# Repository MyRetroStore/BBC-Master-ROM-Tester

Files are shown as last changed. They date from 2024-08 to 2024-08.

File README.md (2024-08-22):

# BBC Master ROM Dumper
An Arduino Mega shield to read and verify the BBC Master 1MBit ROM and compares the ROM images to known CRC-32 values for various ROMs.

## Introduction
Modern EPROM programmers like the TL866 are unable to read the 28 pin 1Mbit ROM used in the BBC Master.  If you are troubleshooting a BBC Master and you don't have a known good BBC Master to test the ROM in, this makes it difficult to troubleshoot. 

I built a shield for the Arduino Mega 2560 which reads the ROM and compares the CRC-32 hash values to know good ROMs found on the internet with a option of displaying the contents of the ROM via the Arduino IDE serial monitor. 

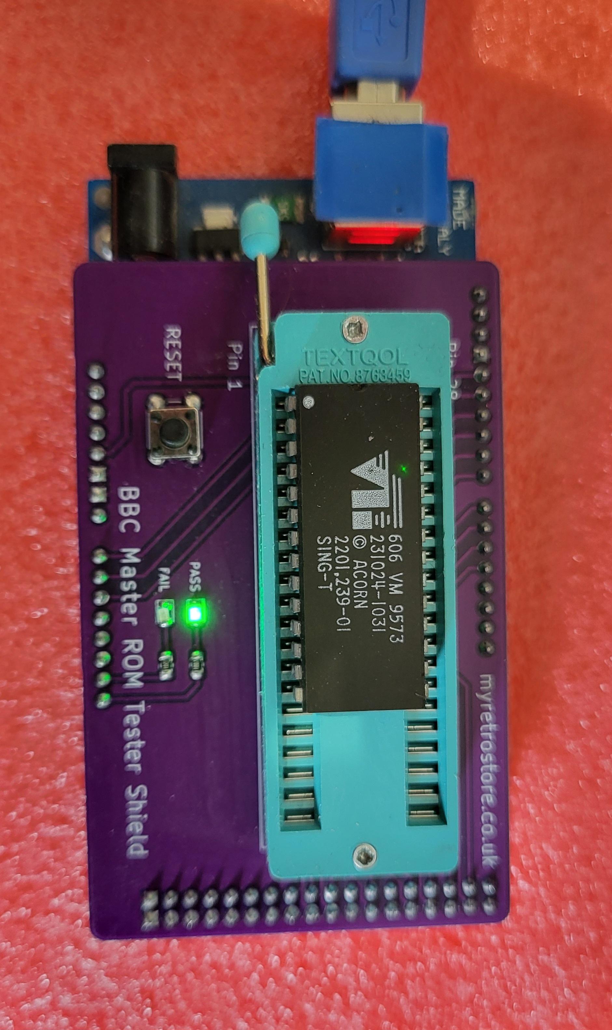
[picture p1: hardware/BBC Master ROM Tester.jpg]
Shield


## Usage

This Arduino sketch was built and tested using Arduino IDE 1.8.19 but should work with later versions.

Before uploading the .ino to the Mega2560, review the config.h file and change the paramaters as required:

- To display ROM contents set ReadOnly to true

Once the code has been uploaded insert the chip (Remove power before inserting the ROM) and open the serial monitor set to 115200 baud.

Program will run and compare the CRC-32 hash of the ROM under test, or display the contents of the ROM.

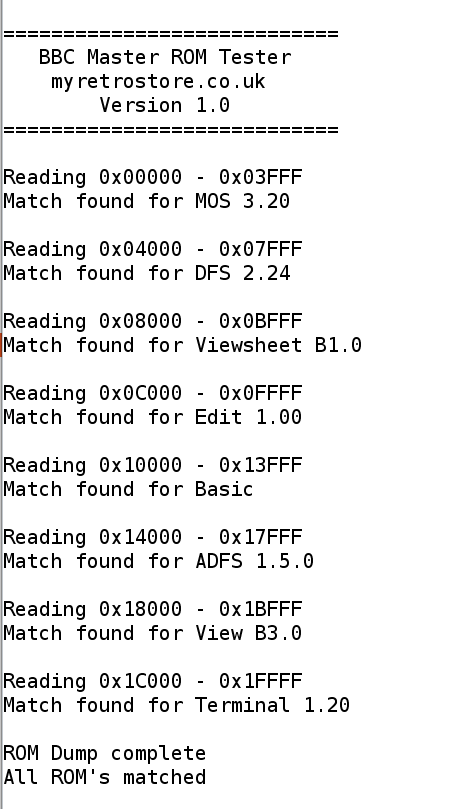
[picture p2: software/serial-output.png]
Serial Output


The Arduino code comes pre-configured with a set of CRC-32 hashes from the common ROM's, but additional hashes can be added using the supplied python [script](https://github.com/MyRetroStore/BBC-Master-ROM-Tester/tree/main/software)

##  Shield

The gerber files for the shield can be found under hardware/gerbers

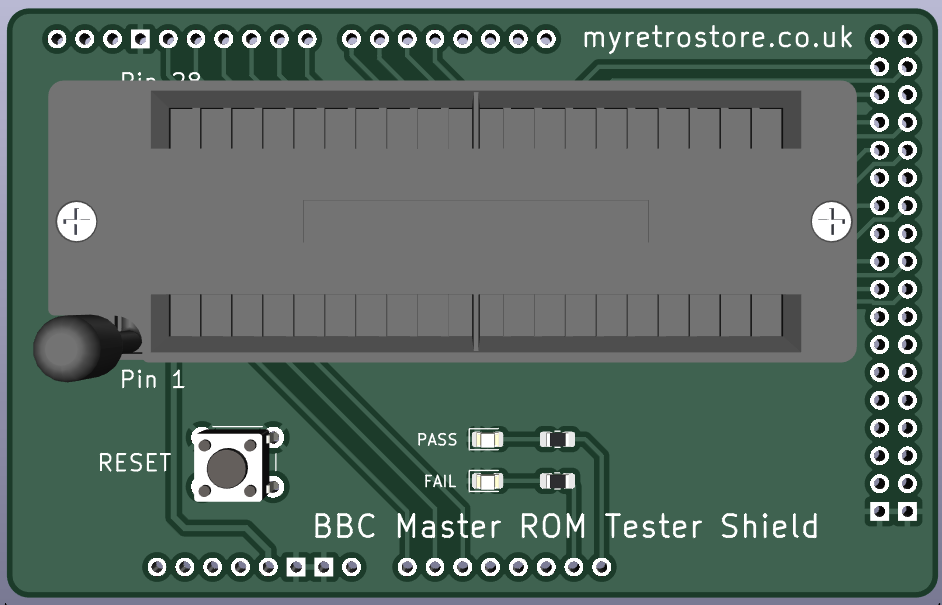
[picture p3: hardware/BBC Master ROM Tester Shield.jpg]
Retro ROM Tester


## BOM
| Reference | Value |
| --- | --- |
| Pass | Green LED 0805 |
| Fail | Red LED 0805 |
| R1/R2 | 2k2 0805 Resistors |
| U1 | 40 Pin ZIF Socket |
| SW1 | Push Button Switch 6x6x6 |
| | 2.54mm SIL Male Headers

## Purchasing

If you don't want build the shield yourself, assembled shields can be purchased from:
- [MyRetroStore](https://myretrostore.co.uk/)
- [eBay](https://www.ebay.co.uk/str/myretrostoreuk)

## License
CC BY-NC-SA 4.0



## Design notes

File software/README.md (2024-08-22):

# BBC Master ROM Tester 

Arduino/

Code for the Arduino Mega2560

Serial Output

Script/

Python script to generate CRC-32 hashes used in the Arduino code.

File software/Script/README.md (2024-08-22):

# Creating CRC-32 hashes

The python script was developed in Linux, but should run on any OS with python 3.x

## Introduction

The python script **generate_crc.py** is used to generate CRC-32 hashes from ROM files. This is useful if the ROM you are testing does not have a CRC-32 hash pre-configured in the Arduino code. 

As the Arduino Mega 2560 has a limited amount of RAM, when reading the ROM the contents, it's read in 4k chunks. A CRC-32 is calculated for each 4Kb bank and then once all 4x4KKb banks are completed a final CRC-32 value is calculated. 
 
 The hashes are stored in the file [crc.h](https://github.com/MyRetroStore/BBC-Master-ROM-Tester/blob/main/software/Arduino/crc.h)

## Usage

Run:
```
./generate_crc.py -i filename
```
This calculates the CRC-32 hash for the ROM binary (filename) and updates the crc.h file. 

 Example:
 ```
 ./generate_crc.py -i ROMs/basic.bin
 ```

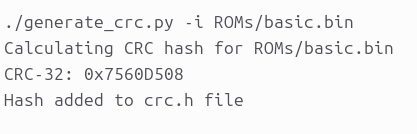
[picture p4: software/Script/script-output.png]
Serial Output


Once completed copy ```crc.h``` back to the Arduino folder and compile and upload the sketch to the Mega2560.

 ## To Do
 - While basic error checking is done in the python script, there is a lot more error checking that cold be done so not all errors will be catered for (Eg if you had to remove the marker text from crc.h then the script will probably throw a weird error)
 - I'm not a programmer so while this script seems to work, it's not the most efficient and there are probably a lot better ways to do things. 

## License
CC BY-NC-SA 4.0

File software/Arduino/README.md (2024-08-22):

# Retro ROM Tester

Arduino code was developed with Arduino IDE 1.8.19 but there is no reason why it should not work with later versions. 

Dependencies:
sDIO2 Library (https://github.com/Locoduino/DIO2)

If you experience intermittent issues reading and validing hashes check that the ROM pins are not corroded. During my testing I found a lot of ROM's that were badly corroded and gave intermittent reading issues until the pins were cleaned up.

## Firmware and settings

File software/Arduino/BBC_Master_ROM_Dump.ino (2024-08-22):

/*
  Copyright: MyRetroStore (myretrostore.co.uk)
  Date: 22 August 2024
  Version 1.0
*/
  
#include <DIO2.h> // include the fast I/O functions
#include "config.h"
#include "MD5.h"
#include "crc.h"
#include <stdint.h>

//----------------------------------------------------------------------
// Global variables
//----------------------------------------------------------------------
const uint32_t POLY = 0xEDB88320;

#define CE 6 
#define LED_Green A7
#define LED_Red A6

boolean hashmatch = false;
uint8_t addressLines[] = {36, 33, 32, 29, 28, 27, 26, A2, 11, 10, 7, 9, A1, 12, 13, A0, 8};
uint8_t dataLines[] = {37, 38, 39, 24, 23, 22, 4, 5};

size_t index = 0;

uint8_t ROM[4100] = {};  // Buffer to hold 4k of ROM
uint16_t ROM_counter = 0;
uint8_t ROM_Byte;

int ledState = HIGH;     // the current state of LED
long addressStart = 0, addressEnd = 0;
long addressCurrent;
uint8_t error_count=0;
uint32_t crc1;
uint32_t crc2;
uint32_t crc3;
uint32_t crc4;


//----------------------------------------------------------------------
// Calculate CRC-32 value
//----------------------------------------------------------------------
uint32_t calculate_crc32(uint32_t crc, uint32_t value) {
  crc ^= value;
  for (uint8_t i = 0; i < 32; i++) {
    if (crc & 1) {
      crc = (crc >> 1) ^ POLY;
    } else {
      crc >>= 1;
    }
  }
  return crc;
}

//----------------------------------------------------------------------
// Toggle LED for feedback during checking
//----------------------------------------------------------------------
void toggleLED()
{
  digitalWrite2(LED_Red, ledState);
  digitalWrite2(LED_Green, !ledState);
  ledState = !ledState;
}

//----------------------------------------------------------------------
// Check if CRC-32 value read is valid
//----------------------------------------------------------------------
void check_crc(uint32_t crc)
{
  hashmatch = false;

  const size_t crcCnt_16k = sizeof crc_16k / sizeof * crc_16k;

  t_crc_16k data;
  ROM_counter = 0;

  char file[32];
  char hash[33];

  for (index = 0; index < crcCnt_16k; index++) {
    readArray(index, data);

    uint32_t hashnumber = strtoul(data.hash, NULL, 16);

    if (crc == hashnumber) {
      hashmatch = true;
      Serial.print("Match found for ");
      Serial.println(data.fileName);
      // toggleLED();
      break;
    }
  }

  if (hashmatch == false) {
    Serial.print("CRC-32 match not found for ");
    Serial.println(crc, HEX);
    error_count++;
  }
}

//----------------------------------------------------------------------
// Read data from data pins
//----------------------------------------------------------------------
uint8_t getData(void)
{
  uint8_t readback;
  char data = 0;
  for (uint8_t i = 0; i < sizeof(dataLines); i++)
  {
    readback = digitalRead2(dataLines[i]);
    data |= readback ? (1 << i) : 0;
  }
  return data;
}

//----------------------------------------------------------------------
// Set Address
//----------------------------------------------------------------------
void setAddr(long address)
{
  for (uint8_t i = 0; i < sizeof(addressLines); i++)
  {
    digitalWrite2(addressLines[i], ((address >> i) & 1));
  }
}

//----------------------------------------------------------------------
// Init I/O Pins
//----------------------------------------------------------------------
void InitialisePins()
{
  pinMode2(LED_Green, OUTPUT);
  pinMode2(LED_Red, OUTPUT);

  digitalWrite2(LED_Green, LOW);
  digitalWrite2(LED_Red, LOW);

  pinMode2(CE, OUTPUT);
  digitalWrite2(CE, HIGH);

  for (int i = 0; i < sizeof(addressLines); i++)
  {
    pinMode2(addressLines[i], OUTPUT);
    digitalWrite2(addressLines[i], LOW);
  }

  for (int i = 0; i < sizeof(dataLines); i++)
  {
    pinMode2(dataLines[i], INPUT);
  }
}

//----------------------------------------------------------------------
// Setup
//----------------------------------------------------------------------
void setup() {
  Serial.begin(115200);
  Serial.println("\n============================");
  Serial.println("   BBC Master ROM Tester");
  Serial.println("    myretrostore.co.uk");
  Serial.print("        "); Serial.println(VERSION);
  Serial.println("============================");
}

//----------------------------------------------------------------------
// Function to read array from PROGMEM
//----------------------------------------------------------------------
void readArray(int index, t_crc_16k &data) {
  memcpy_P(&data, &crc_16k[index], sizeof(t_crc_16k));
}

//----------------------------------------------------------------------
// Loop through 4 x 4k address locations and check CRC hashes
//----------------------------------------------------------------------
void read_data()
{
  char hexString[10]; 

  if (addressEnd != 0 ) // This is to ensure to only increase the address in the 2nd loop onwards
  {
    addressStart = addressStart + 0x4000;
  }

  addressEnd = addressStart + 0x4000;

  Serial.print("\nReading 0x");
  sprintf(hexString, "%05lX", addressStart);      // Pad value to 5 places
  Serial.print(hexString);
  Serial.print(" - 0x");
  sprintf(hexString, "%05lX", addressEnd - 1);
  Serial.println(hexString);

  for (long address = addressStart; address < addressEnd; address++)
  {
    setAddr(address);   //SetAddress(address); // tells the ROM the byte we want ...
    delayMicroseconds(1);
    digitalWrite2(CE, LOW);
    ROM_Byte = getData();
    digitalWrite2(CE, HIGH); // Disable CE

    ROM[ROM_counter] = ROM_Byte;
    ROM_counter++;

    //-----------------------------------------------------------------------
    // Calc first CRC
    //-----------------------------------------------------------------------
    if  (address == (addressStart + 0x0FFF ))
    {
      uint32_t crc = 0xFFFFFFFF;
      for (size_t i = 0; i < 4096; i++) {
        crc = calculate_crc32(crc, ROM[i]);
      }
      crc ^= 0xFFFFFFFF;
      crc1 = crc;
      //  Serial.println(crc1, HEX);
      toggleLED();

      ROM_counter = 0;
    }

    //-----------------------------------------------------------------------
    // Check 2nd CRC
    //-----------------------------------------------------------------------
    if  (address == (addressStart + 0x1FFF ))
    {
      uint32_t crc = 0xFFFFFFFF;
      for (size_t i = 0; i < 4096; i++) {
        crc = calculate_crc32(crc, ROM[i]);
      }
      crc ^= 0xFFFFFFFF;
      crc2 = crc;
      //   Serial.println(crc2, HEX);
      toggleLED();
      ROM_counter = 0;
    }

    //-----------------------------------------------------------------------
    // Check 3rd CRC
    //-----------------------------------------------------------------------
    if  (address == (addressStart + 0x2FFF ))
    {
      uint32_t crc = 0xFFFFFFFF;
      for (size_t i = 0; i < 4096; i++) {
        crc = calculate_crc32(crc, ROM[i]);
      }
      crc ^= 0xFFFFFFFF;
      crc3 = crc;
      //  Serial.println(crc3, HEX);
      toggleLED();
      ROM_counter = 0;
    }

    //-----------------------------------------------------------------------
    // Check 4th CRC
    //-----------------------------------------------------------------------
    if  (address == (addressStart + 0x3FFF ))
    {
      uint32_t crc = 0xFFFFFFFF;
      for (size_t i = 0; i < 4096; i++) {
        crc = calculate_crc32(crc, ROM[i]);
      }
      crc ^= 0xFFFFFFFF;
      crc4 = crc;
      //  Serial.println(crc4, HEX);
      toggleLED();
      ROM_counter = 0;
    }
  }

  uint32_t crc = 0xFFFFFFFF;

  // Combine CRC values
  crc = calculate_crc32(crc, crc1);
  crc = calculate_crc32(crc, crc2);
  crc = calculate_crc32(crc, crc3);
  crc = calculate_crc32(crc, crc4);

  // Finalize the CRC calculation
  crc ^= 0xFFFFFFFF;

  check_crc(crc); // Check if CRC matches
}

//----------------------------------------------------------------------
// Print HEX to screen for ReadOnly mode
//----------------------------------------------------------------------

void debug()
{
  char str[40];

  for (long address = DebugStartAddress; address < DebugEndAddress + 1; address++)
  {
    setAddr(address);   // tells the ROM the byte we want ...
    delayMicroseconds(1);
    digitalWrite2(CE, LOW);
    ROM_Byte = getData();
    digitalWrite2(CE, HIGH); // Disable CE

    if (address % 16 == 0)
    {
      ///  sprintf(str, "\r\n0x%05lX", address);
      ///  Serial.print(str);
      Serial.println("");
    }

    sprintf(str, " %02X", ROM_Byte);
    Serial.print(str);
  }

  Serial.print("\r\n\nDump complete from 0x");
  Serial.print(DebugStartAddress, HEX);
  Serial.print(" - 0x");
  Serial.println(DebugEndAddress, HEX);
}

//----------------------------------------------------------------------
// Main Loop
//----------------------------------------------------------------------
void loop() {

  const size_t crcCnt_16k = sizeof crc_16k / sizeof * crc_16k;
  t_crc_16k data;

  InitialisePins();

  if (ReadOnly == false) {
    // Routing for reading ROM, calculating CRC and checking
    for (int i = 0; i < 8; i++) { // 8 ROMs of 128k each
      read_data();
    }
  } else {
    debug();    //Only dump ROM due to config setting
  }

  Serial.println("\nROM Dump complete");

  if (error_count == 0) {
    digitalWrite(LED_Red, LOW);
    digitalWrite(LED_Green, HIGH);
    Serial.println("All ROM's matched");
  } else {
    Serial.print(error_count); Serial.println(" CRC-32 value not found");
    digitalWrite(LED_Red, HIGH);
    digitalWrite(LED_Green, LOW);
  }

  while (1);
}

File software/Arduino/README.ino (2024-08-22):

/*
  Author: MyRetroStore (myretrostore.co.uk)
  Date: 22 August 2024
  Version 1.0

  Code to read the 28 pin BBC Master 128Kb (1Mbit) ROM and compare it against known ROM dumps
  using a Arduino Mega 2560 Shield.

  The BBC Master ROM is a strange 28 pin ROM that cannot be read with a standard EPROM programmer like
  the TL866 which is by I designed this shield. 

  As the Arduino Mega 2560 only has a limited amount of RAM the whole 128K cannnot be read in
  one go, so it's read in 4K chunks and compared to CRC-32 hashes of the original ROM dump.

  This will check if your ROM is valid or corrupted, and can be also used to dump it's contents. 

  Tested against BBC Master ROM Chip 231024-1031 and RetroClinic MultiOS ROM

  You can optionally set the ReadOnly flag to only read the ROM and not do any checks.
  (See config.h)

  To generate the CRC-32 values see the python script on the github page:
  https://github.com/MyRetroStore/BBC-Master-ROM-Tester

  Dependencies:
  DIO2 Library (https://github.com/Locoduino/DIO2)

  Arduino code was built and compiled on Arduino 1.8.19

*/

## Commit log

2024-08-22 Add gerber files
    [BBC Master ROM Tester-B_Cu.gbr, BBC Master ROM Tester-B_Mask.gbr, BBC Master ROM Tester-B_Paste.gbr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]
2024-08-22 Update BOM
